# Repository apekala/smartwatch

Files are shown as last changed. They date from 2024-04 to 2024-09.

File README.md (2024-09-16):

# Smartwatch with Step Counter and BLE Connectivity

A smartwatch featuring a step counter, BLE connection for notifications, and automatic time synchronization with a mobile phone. This project includes a custom-designed PCB, firmware written in C using Zephyr RTOS, and a companion mobile app developed in Flutter.

## Features
- **Step Counter:** Tracks steps using the BMA456 accelerometer.
- **BLE Connectivity:** Connects to a mobile phone for notifications and time synchronization.
- **E-paper Display:** Provides a clear and power-efficient display.
- **Vibration Alerts:** Integrated vibration motor for notifications.
- **Custom 3D-Printed Case:** Durable and stylish housing for all components.

## Hardware Components
- **Custom PCB:** Designed to integrate all components seamlessly.
- **nRF52833 Microcontroller:** Handles processing and BLE communication.
- **npm1300 PMIC:** Power management for efficient battery usage.
- **BMA456 Accelerometer:** Used for accurate step counting.
- **E-paper Display:** Low-power display for showing time, steps, and notifications.
- **Vibration Motor:** Provides haptic feedback for notifications.
- **Li-Po Battery:** Rechargeable battery for powering the smartwatch.
- **3D-Printed Case:** Custom-designed to house the hardware.

## Software
- **Firmware:** Developed in C using Zephyr RTOS for reliable and real-time performance.
- **Mobile App:** Built with Flutter to handle BLE communication and manage smartwatch settings.
- **BLE Communication:** Allows the smartwatch to sync time and receive notifications from the phone.

# Pictures


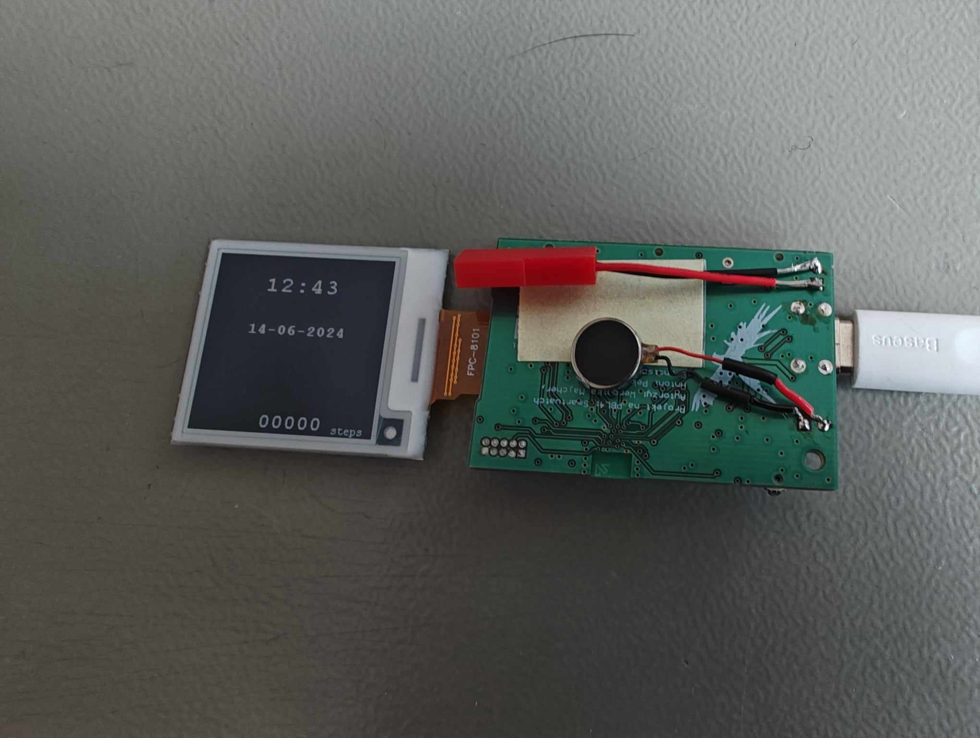
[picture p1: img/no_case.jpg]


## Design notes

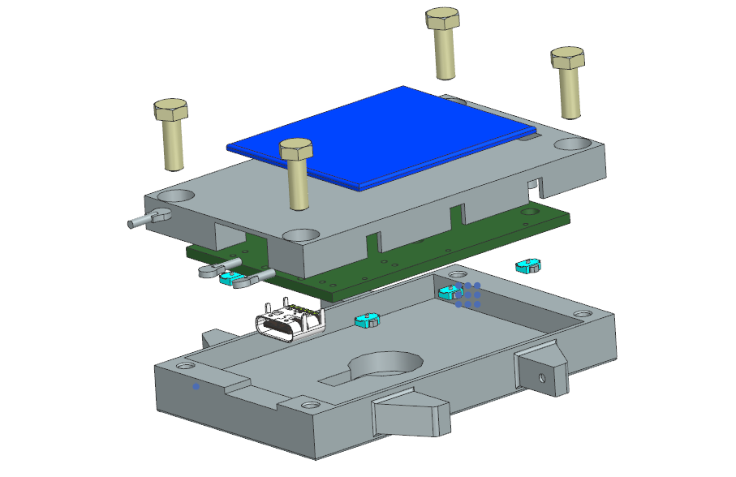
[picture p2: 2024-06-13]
MODEL/img/Explosion.png

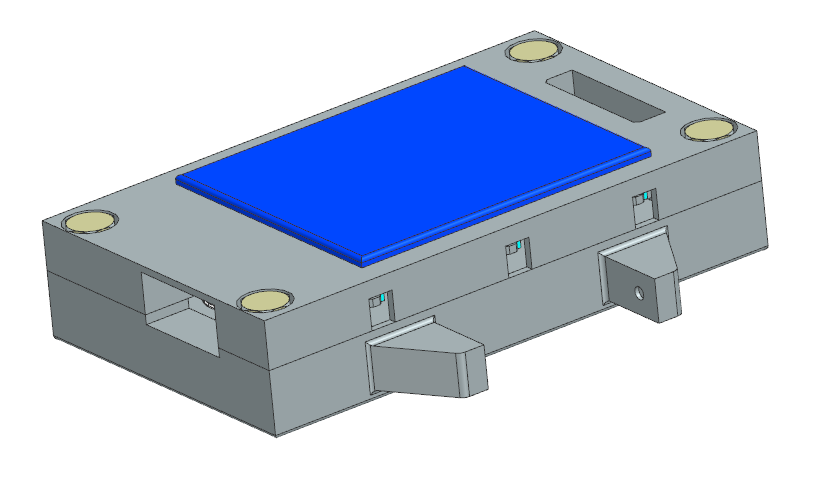
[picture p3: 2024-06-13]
MODEL/img/model.png

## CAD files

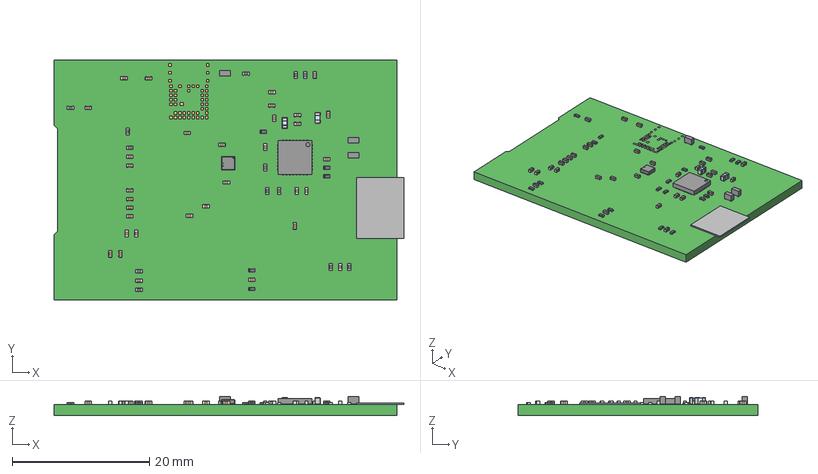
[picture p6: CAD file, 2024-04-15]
HARDWARE/PCB_smartwatch/Project Outputs for Free Documents/ExportSTEP/Demo_PCB.step
51.0 x 35.0 x 2.84 mm
User Library-res0402-1 x 18
User Library-cap_0402 x 33
ThermalPin
PinsArrayLR
PinsArrayTB
Extruded x 49
BOSCH logo
User Library-INDC1608X___ x 2
Pins x 3

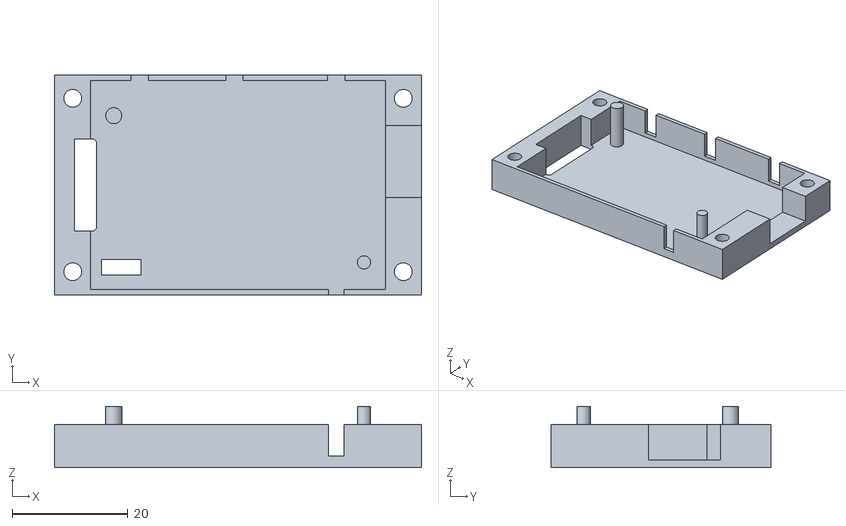
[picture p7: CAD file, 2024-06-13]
MODEL/STL/pokrywa_1.stl
63.5 x 38.0 x 10.6

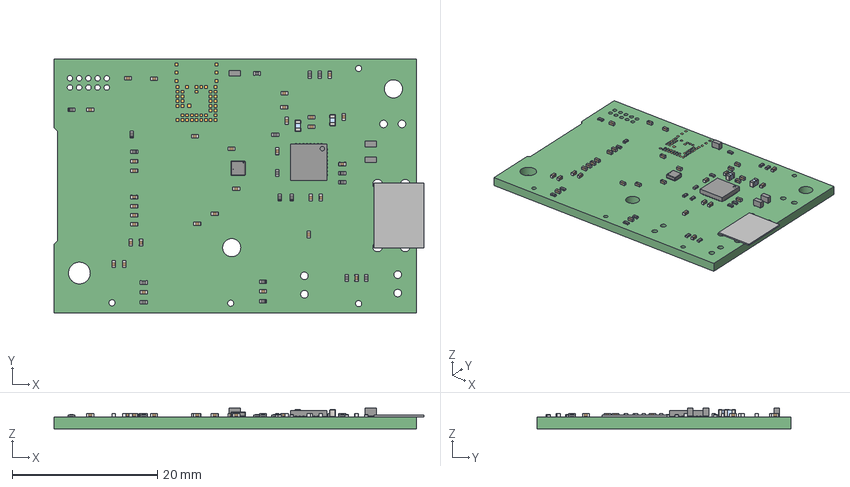
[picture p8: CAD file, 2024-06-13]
MODEL/smartwatch.step
51.0 x 35.0 x 2.84 mm
User Library-res0402-1 x 18
User Library-cap_0402 x 33
ThermalPin
PinsArrayLR
PinsArrayTB
Extruded x 49
BOSCH logo
User Library-INDC1608X___ x 2
Pins x 3

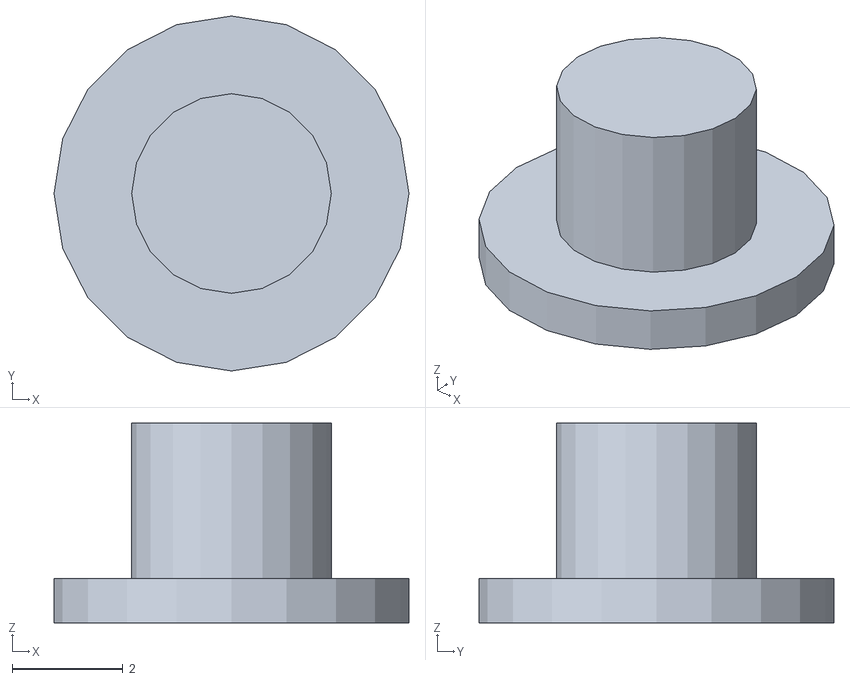
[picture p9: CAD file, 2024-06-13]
MODEL/STL/uszczelka2.stl
6.40 x 6.40 x 3.60

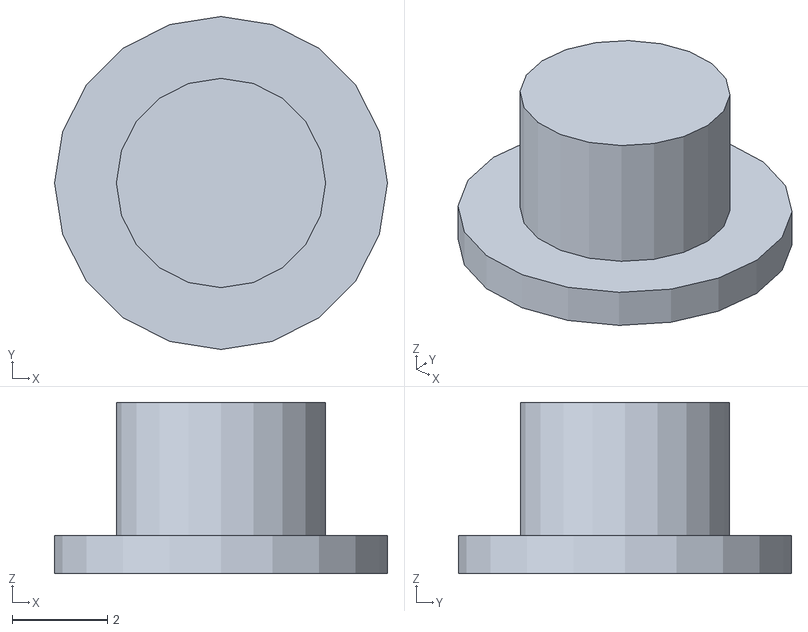
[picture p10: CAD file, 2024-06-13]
MODEL/STL/uszczelka.stl
7.00 x 7.00 x 3.60

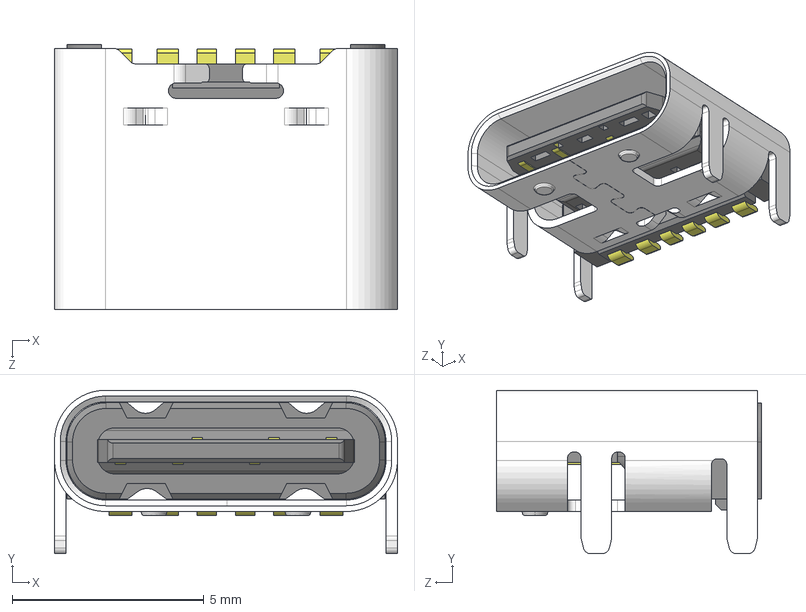
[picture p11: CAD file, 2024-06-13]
MODEL/UJC-HP2-3-SMT-TR.stp
8.94 x 4.26 x 6.90 mm

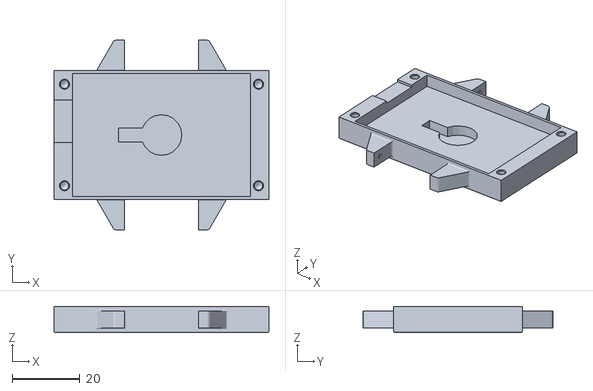
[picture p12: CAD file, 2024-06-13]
MODEL/STL/dolna_obudowa_3.stl
63.5 x 56.0 x 7.80

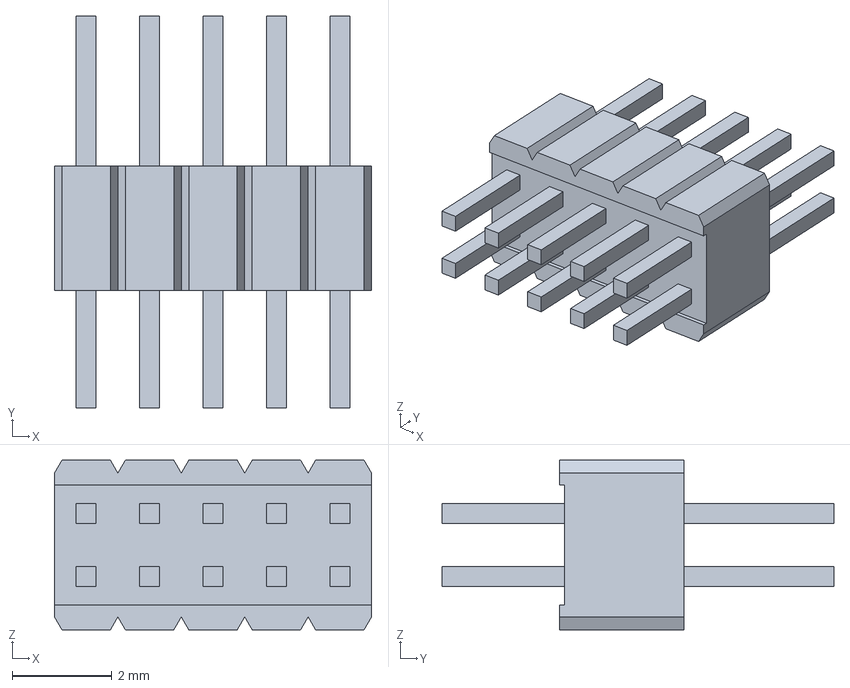
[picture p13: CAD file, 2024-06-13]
MODEL/20021111-00010T1LF.stp
6.35 x 7.85 x 3.40 mm

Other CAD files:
HARDWARE/PCB_smartwatch/Project Outputs for Free Documents/AutoCAD PCB/Demo_PCB.DWG
HARDWARE/PCB_smartwatch/Project Outputs for PCB_smartwatch/AutoCAD PCB/Demo_PCB.DWG
HARDWARE/PCB_smartwatch/Project Outputs for PCB_smartwatch/ExportSTEP/Demo_PCB.step
MODEL/1.prt
MODEL/2.prt
MODEL/20021111-00010T1LF_stp.prt
MODEL/3.prt
MODEL/6132891472.prt
MODEL/6132892112.prt
MODEL/6132898752.prt
MODEL/6263220400.prt
MODEL/6263222960.prt
MODEL/6263223120.prt
MODEL/BOSCH logo.prt
MODEL/Board.prt
MODEL/Body.prt
MODEL/Body19030.prt
MODEL/Body19596.prt
MODEL/C1.prt
MODEL/C10.prt
MODEL/C11.prt
MODEL/C12.prt
MODEL/C13.prt
MODEL/C14.prt
MODEL/C15.prt
MODEL/C16.prt
MODEL/C17.prt
MODEL/C18.prt
MODEL/C19.prt
MODEL/C2.prt
MODEL/C20.prt
MODEL/C21.prt
MODEL/C22.prt
MODEL/C23.prt
MODEL/C24.prt
MODEL/C25.prt
MODEL/C26.prt
MODEL/C27.prt
MODEL/C28.prt
MODEL/C29.prt
MODEL/C3.prt
MODEL/C30.prt
MODEL/C31.prt
MODEL/C32.prt
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

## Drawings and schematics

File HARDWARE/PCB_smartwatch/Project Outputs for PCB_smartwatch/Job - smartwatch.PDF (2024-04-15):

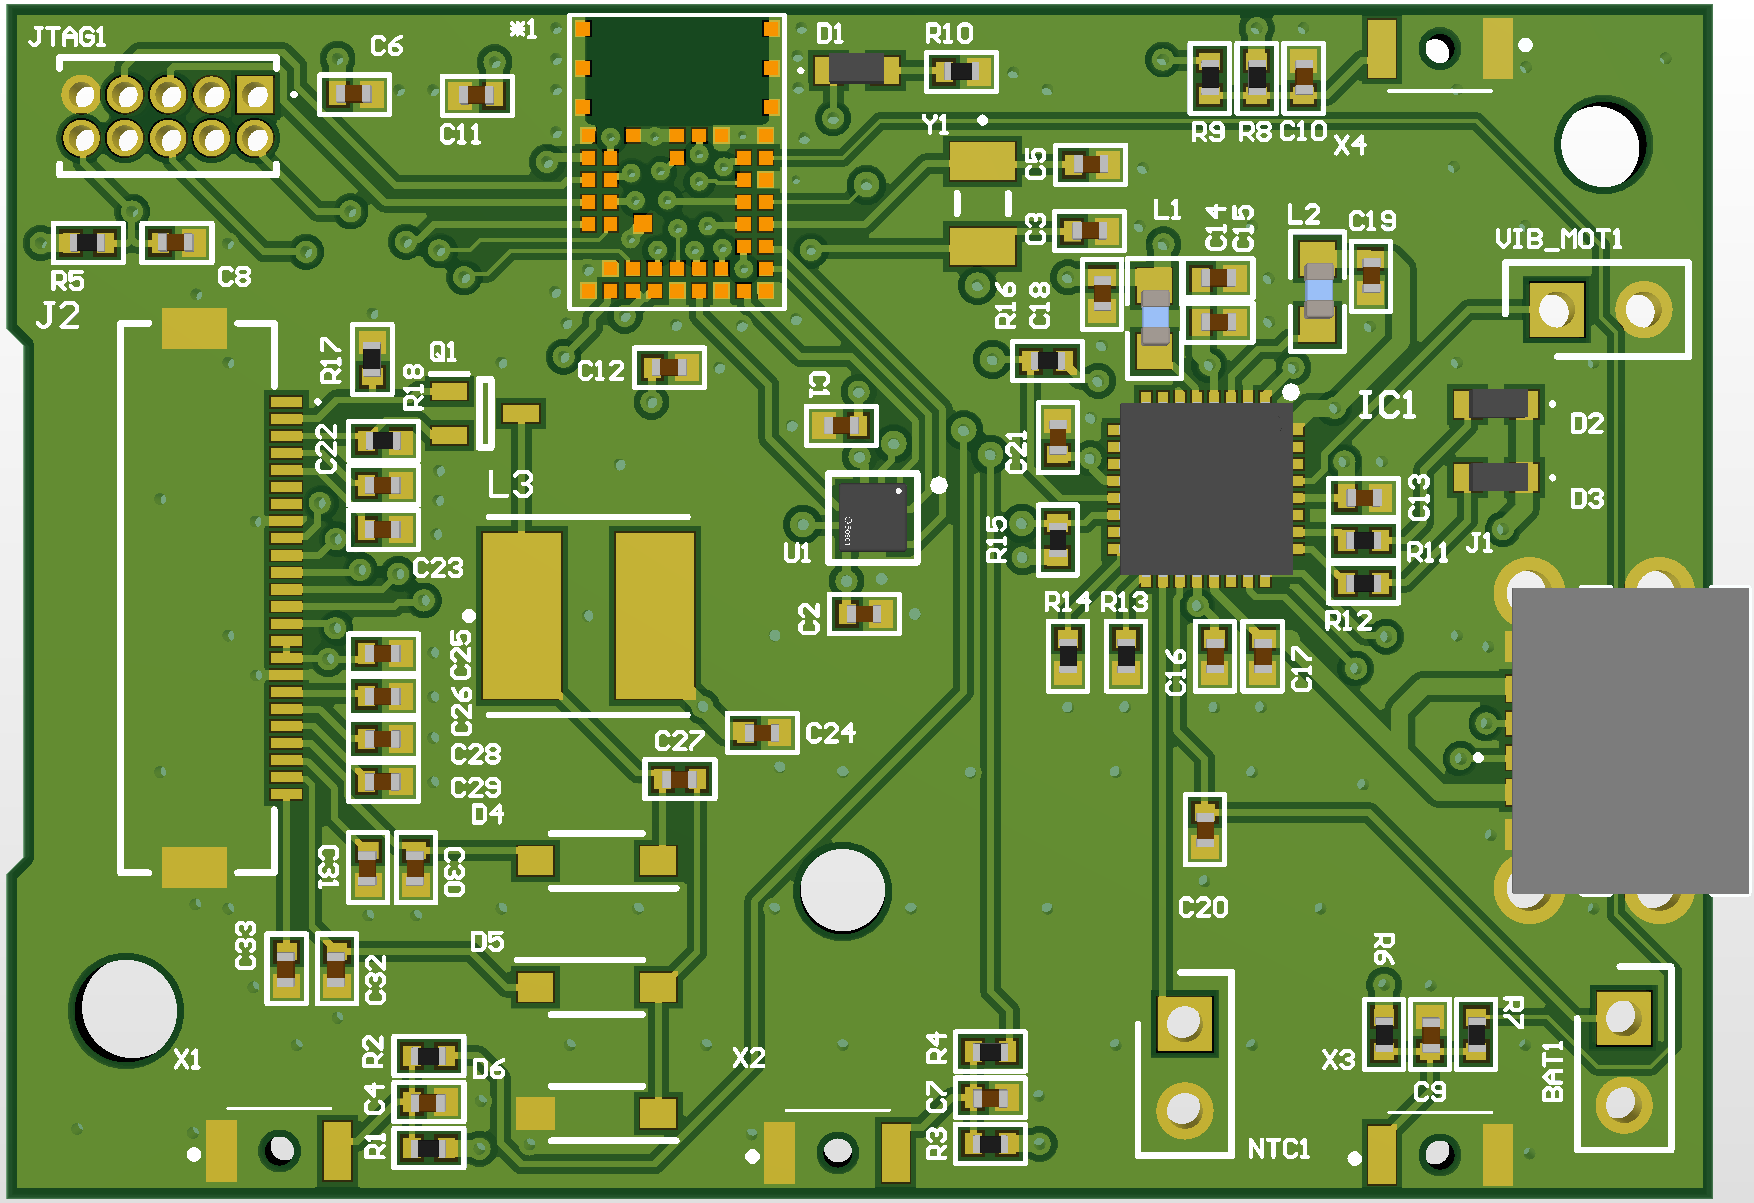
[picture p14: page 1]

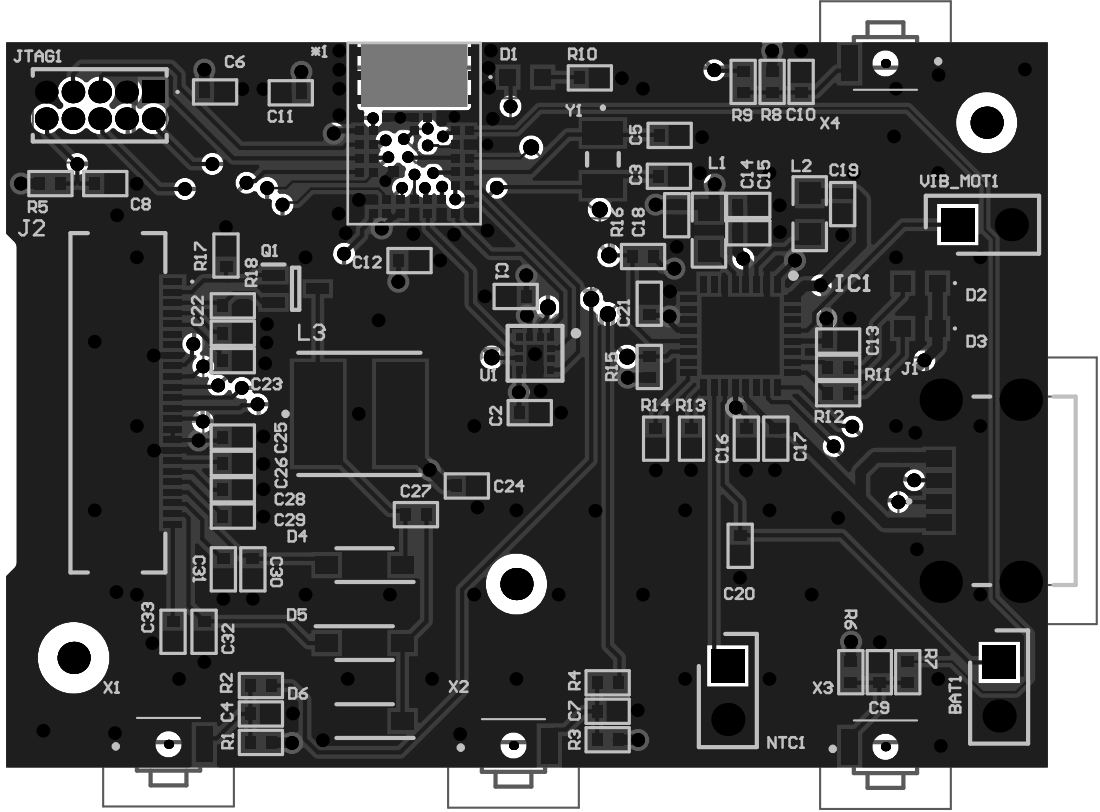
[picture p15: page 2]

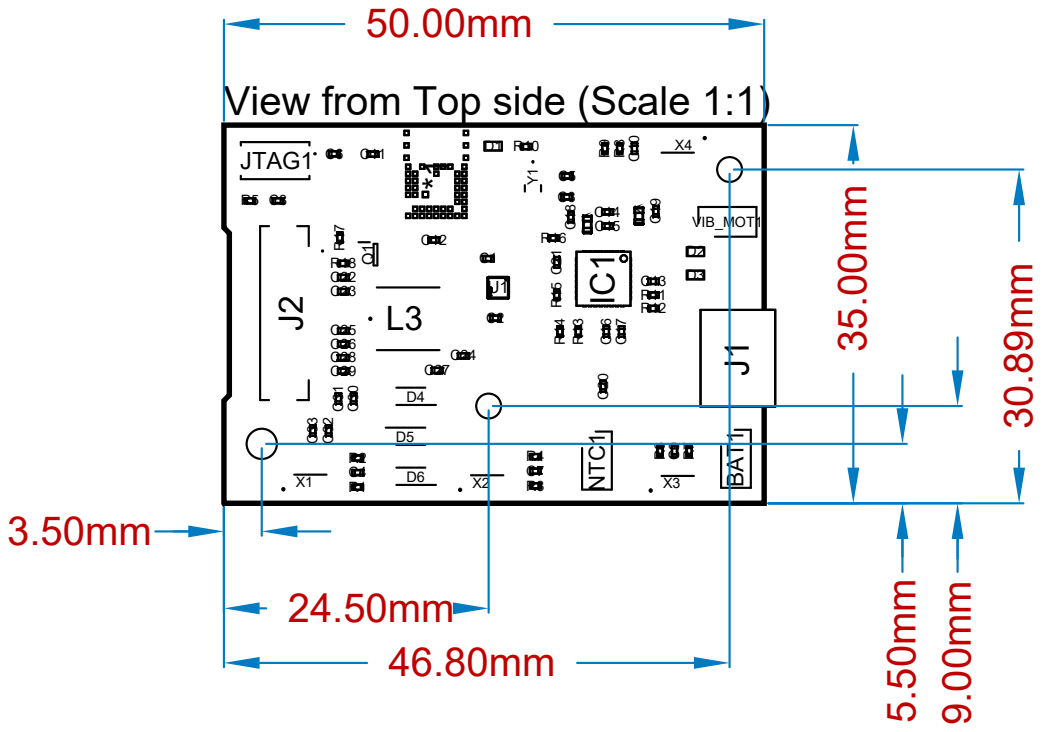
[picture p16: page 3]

View from Top side (Scale 1:1)
JTAG1J2

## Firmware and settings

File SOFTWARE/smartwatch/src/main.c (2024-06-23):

#include <zephyr/device.h>
#include <zephyr/devicetree.h>
#include <zephyr/drivers/counter.h>
#include <zephyr/drivers/gpio.h>
#include <zephyr/drivers/i2c.h>
#include <zephyr/kernel.h>
#include <zephyr/logging/log.h>
#include <zephyr/sys/printk.h>

#include "BLE/BLE.h"
#include "RTC/rtc.h"
#include "UI/display.h"
#include "UI/ui_controller.h"
#include "UI/vibration.h"
#include "accelerometer/accelerometer.h"
#include "power/npm1300.h"
#include "watch_controller/watch_controller.h"

#define DISPLAY_STACK_SIZE 16384
#define DISPLAY_THREAD_PRIORITY 5

K_THREAD_STACK_DEFINE(display_stack_area, DISPLAY_STACK_SIZE);
struct k_thread display_thread_data;

#define LED0_NODE DT_ALIAS(led0)
extern const struct gpio_dt_spec led = GPIO_DT_SPEC_GET(LED0_NODE, gpios);

LOG_MODULE_REGISTER(main, LOG_LEVEL_DBG);

int main(void) {
    int ret;
    if (!device_is_ready(led.port)) {
        return -1;
    }
    ret = gpio_pin_configure_dt(&led, GPIO_OUTPUT_ACTIVE);
    if (ret < 0) {
        return -1;
    }

    gpio_pin_set_dt(&led, 1);

    npm_init();
    k_msleep(1000);
    ui_vibration_init();

    ui_vibrate(1000);

    watch_init();
    rtc_init();
    accel_init();
    ble_init();

    k_tid_t my_tid = k_thread_create(&display_thread_data, display_stack_area,
                                     K_THREAD_STACK_SIZEOF(display_stack_area),
                                     ui_screen_refresh_thread,
                                     NULL, NULL, NULL,
                                     DISPLAY_THREAD_PRIORITY, 0, K_NO_WAIT);

    ui_init();

    watch_display_update();

    LOG_INF("Initialization complete");

    for (;;) {
        gpio_pin_toggle_dt(&led);
        k_msleep(100);
    }

    LOG_INF("end");
    return 0;
}

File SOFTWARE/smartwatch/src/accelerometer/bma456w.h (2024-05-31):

/**
* Copyright (c) 2023 Bosch Sensortec GmbH. All rights reserved.
*
* BSD-3-Clause
*
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
* 1. Redistributions of source code must retain the above copyright
*    notice, this list of conditions and the following disclaimer.
*
* 2. Redistributions in binary form must reproduce the above copyright
*    notice, this list of conditions and the following disclaimer in the
*    documentation and/or other materials provided with the distribution.
*
* 3. Neither the name of the copyright holder nor the names of its
*    contributors may be used to endorse or promote products derived from
*    this software without specific prior written permission.
*
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
* @file       bma456w.h
* @date       2023-07-05
* @version    V2.29.0
*
*/

/**
 * \ingroup bma4xy
 * \defgroup bma456w BMA456W
 * @brief Sensor driver for BMA456W sensor
 */

#ifndef BMA456W_H
#define BMA456W_H

#include <zephyr/logging/log.h>
#include <zephyr/logging/log_ctrl.h>

#ifdef __cplusplus
extern "C" {
#endif
#include "bma4.h"

/**\name Chip ID of BMA456W sensor */
#define BMA456W_CHIP_ID                                  UINT8_C(0x16)

/**\ Configuration ID start position of BMA456W sensor */
#define BMA456W_CONFIG_ID_START_ADDR                     UINT8_C(72)

/**\name Sensor feature size */
#define BMA456W_FEATURE_SIZE                             UINT8_C(76)
#define BMA456W_ANY_MOT_LEN                              UINT8_C(4)

/**\name Feature offset address */
#define BMA456W_ANY_MOT_OFFSET                           UINT8_C(0x00)
#define BMA456W_NO_MOT_OFFSET                            UINT8_C(0x04)
#define BMA456W_STEP_CNTR_PARAM_OFFSET                   UINT8_C(0x08)
#define BMA456W_STEP_CNTR_OFFSET                         UINT8_C(0x3A)
#define BMA456W_WRIST_WEAR_WAKEUP_OFFSET                 UINT8_C(0x3C)
#define BMA456W_WRIST_WEAR_WAKEUP_PARAM_OFFSET           UINT8_C(0x3E)
#define BMA456W_CONFIG_ID_OFFSET                         UINT8_C(0x48)
#define BMA456W_AXES_REMAP_OFFSET                        UINT8_C(0x4A)

/**\name Read/Write Lengths */
#define BMA456W_RD_WR_MIN_LEN                            UINT8_C(2)
#define BMA456W_NO_MOT_RD_WR_LEN                         (BMA456W_ANY_MOT_LEN + BMA456W_NO_MOT_OFFSET)

/*! @name Maximum valid read write length is size of config file array */
#define BMA456W_RD_WR_MAX_LEN                            ((uint16_t)sizeof(bma456w_config_file))

/**************************************************************/
/**\name    Step Counter/Detector/Activity */
/**************************************************************/
/**\name Step counter/activity enable macros */
#define BMA456W_STEP_CNTR_EN_MSK                         UINT8_C(0x10)
#define BMA456W_STEP_ACT_EN_MSK                          UINT8_C(0x20)

/**\name Step counter water-mark macros */
#define BMA456W_STEP_CNTR_WM_MSK                         UINT16_C(0x03FF)

/**\name Step counter reset macros */
#define BMA456W_STEP_CNTR_RST_POS                        UINT8_C(2)
#define BMA456W_STEP_CNTR_RST_MSK                        UINT8_C(0x04)

/**\name Step detector enable macros */
#define BMA456W_STEP_DETECTOR_EN_POS                     UINT8_C(3)
#define BMA456W_STEP_DETECTOR_EN_MSK                     UINT8_C(0x08)

/**\name Wrist-wear enable macros */
#define BMA456W_WRIST_WEAR_WAKEUP_EN_MSK                 UINT8_C(0x10)
#define BMA456W_WRIST_WEAR_WAKEUP_EN_POS                 UINT8_C(4)

/**\name Step count output length */
#define BMA456W_STEP_CNTR_DATA_SIZE                      UINT8_C(4)

/**************************************************************/
/**\name    Any/No-Motion */
/**************************************************************/
/**\name Any/No-motion threshold macros */
#define BMA456W_ANY_NO_MOT_THRES_MSK                     UINT16_C(0x07FF)

/**\name Any/No-motion duration macros */
#define BMA456W_ANY_NO_MOT_DUR_MSK                       UINT16_C(0x1FFF)

/**\name Any/No-motion enable macros */
#define BMA456W_ANY_NO_MOT_AXIS_EN_POS                   UINT8_C(0x0D)
#define BMA456W_ANY_NO_MOT_AXIS_EN_MSK                   UINT16_C(0xE000)

/**************************************************************/
/**\name    Wrist wear wakeup */
/**************************************************************/
/**\name Mask definition for minimum angle focus */
#define BMA456W_WRIST_WEAR_WAKEUP_MIN_ANG_FOCUS_MSK      UINT16_C(0xFFFF)

/**\name Mask definition for minimum angle non focus */
#define BMA456W_WRIST_WEAR_WAKEUP_MIN_ANG_NON_FOCUS_MSK  UINT16_C(0xFFFF)

/**\name Mask definition for angle landscape right */
#define BMA456W_WRIST_WEAR_WAKEUP_ANG_LSCAPE_RHT_MSK     UINT8_C(0xFF)

/**\name Mask definition for angle landscape left  */
#define BMA456W_WRIST_WEAR_WAKEUP_ANG_LSCAPE_LEFT_MSK    UINT16_C(0XFF00)

/**\name Position definition for angle landscape left */
#define BMA456W_WRIST_WEAR_WAKEUP_ANG_LSCAPE_LEFT_POS    UINT8_C(8)

/**\name Mask definition for angle portrait down  */
#define BMA456W_WRIST_WEAR_WAKEUP_ANG_PORTRAIT_DOWN_MSK  UINT8_C(0xFF)

/**\name Mask definition for angle portrait up */
#define BMA456W_WRIST_WEAR_WAKEUP_ANG_PORTRAIT_UP_MSK    UINT16_C(0xFF00)

/**\name Position definition for angle portrait up */
#define BMA456W_WRIST_WEAR_WAKEUP_ANG_PORTRAIT_UP_POS    UINT8_C(8)

/**\name Mask definition for minimum duration moved */
#define BMA456W_WRIST_WEAR_WAKEUP_MIN_DUR_MOVED_MSK      UINT8_C(0xFF)

/**\name Mask definition for minimum duration quite */
#define BMA456W_WRIST_WEAR_WAKEUP_MIN_DUR_QUITE_MSK      UINT16_C(0xFF00)

/**\name Position definition for minimum duration quite */
#define BMA456W_WRIST_WEAR_WAKEUP_MIN_DUR_QUITE_POS      UINT8_C(8)

/**************************************************************/
/**\name    User macros */
/**************************************************************/
/**\name Any-motion/No-motion axis enable macros */
#define BMA456W_X_AXIS_EN                                UINT8_C(0x01)
#define BMA456W_Y_AXIS_EN                                UINT8_C(0x02)
#define BMA456W_Z_AXIS_EN                                UINT8_C(0x04)
#define BMA456W_EN_ALL_AXIS                              UINT8_C(0x07)
#define BMA456W_DIS_ALL_AXIS                             UINT8_C(0x00)

/**\name Feature enable macros for the sensor */
#define BMA456W_STEP_CNTR                                UINT8_C(0x01)
#define BMA456W_STEP_ACT                                 UINT8_C(0x02)
#define BMA456W_WRIST_WEAR_WAKEUP                        UINT8_C(0x04)

/**\name Interrupt status macros */
#define BMA456W_STEP_CNTR_INT                            UINT8_C(0x02)
#define BMA456W_ACTIVITY_INT                             UINT8_C(0x04)
#define BMA456W_WRIST_WEAR_WAKEUP_INT                    UINT8_C(0x08)
#define BMA456W_ANY_MOT_INT                              UINT8_C(0x20)
#define BMA456W_NO_MOT_INT                               UINT8_C(0x40)
#define BMA456W_ERROR_INT                                UINT8_C(0x80)
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

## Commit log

2024-03-19 add empty project
    [PCB_smartwatch.PrjPcb]
2024-03-19 add acceletometer schema
    [PCB_smartwatch.PrjPcb, Schlib1.SchLib, accelerometer.SchDoc]
2024-03-20 add vibration schema
    [Schlib1.SchLib, accelerometer.SchDoc]
2024-03-20 add lfxo oscilator schema
    [32.768_crystal.SchDoc, PCB_smartwatch.PrjPcb, Schlib1.SchLib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]
2024-03-20 import button
    [32.768_crystal.SchDoc, PCB_smartwatch.PrjPcb, accelerometer.SchDoc]
2024-03-20 chance oscilator capacitor value to 18pF
    [32.768_crystal.SchDoc, PCB_smartwatch.PrjPcb, Schlib1.SchLib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]
2024-03-21 Add e-Paper
    [PCB_smartwatch.PrjPcb, e-Paper.PcbLib, e-Paper.SchLib]
2024-03-21 Add NPM1300
    [PCB_smartwatch.PrjPcb, usb.SchDoc, zasilanie.SchDoc]
2024-03-21 npm1300 ready for final check
    [PcbLib-zasilanie.PcbLib, Schlib-zasilanie.SchLib, Schlib1-zasilanie.SchLib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]
2024-03-21 Add BL653, Rename display
    [1.54inch_e-Paper.SchDoc, BL653.SchDoc, BL653u.PcbLib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]
2024-03-21 Remove crystal, Add BL635 ports e-Paper and accelerometer
    [1.54inch_e-Paper.SchDoc, 32.768_crystal.SchDoc, BL653.SchDoc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]
2024-03-21 Update e-Paper library
    [e-Paper.SchLib]
2024-03-21 Add JTAG
    [BL653.SchDoc, BL653u.PcbLib, BL653u.SchLib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]
2024-03-22 npm1300 modified, usb sheet no longer needed
    [Schlib1-zasilanie.SchLib, usb.SchDoc, zasilanie.SchDoc]
2024-03-22 Add Footprints
    [1.54inch_e-Paper.SchDoc, BL653.SchDoc, BL653u.PcbLib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]
2024-03-22 Add zasilanie I2C Ports and VCC
    [BL653.SchDoc, PCB_smartwatch.PrjPcb, usb.SchDoc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]
2024-03-22 consultations with Dominik
    [Schlib1-zasilanie.SchLib, zasilanie.SchDoc]
2024-03-22 cosmetic changes in npm1300
    [PCB_smartwatch.PrjPcb, zasilanie.SchDoc]
2024-03-26 libraries and footprints - power
    [PCB_smartwatch.PrjPcb, PcbLib-zasilanie.PcbLib, Schlib1-zasilanie.SchLib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]
2024-03-27 layers in footprints configured - npm and usb
    [PcbLib-zasilanie.PcbLib, Schlib1-zasilanie.SchLib, e-Paper.PcbLib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]
2024-03-27 Add inductor footprint, change resistor schamtic, Add templates parameters
    [1.54inch_e-Paper.SchDoc, BL653.SchDoc, BL653u.SchLib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]
2024-03-28 add buttons and led
    [BL653.SchDoc, Schlib1.SchLib, accelerometer.SchDoc]
2024-03-28 changes in power library, inne pcb library added, slight corrections in footprints
    [BL653.SchDoc, BL653u.PcbLib, PCB_smartwatch.PrjPcb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]
2024-03-28 bl changed to 2.5 mm
    [1.54inch_e-Paper.SchDoc, BL653.SchDoc, BL653u.SchLib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]
2024-03-29 pcb_demo.pcbdoc added
    [Demo_PCB.PcbDoc]
2024-03-29 ready to be send, although some footprints missing - to be asked
    [BL653.SchDoc, PCB_smartwatch.PrjPcb, Schlib1-zasilanie.SchLib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]
2024-04-01 small changes + ntc footprint
    [1.54inch_e-Paper.SchDoc, BL653.SchDoc, Schlib1-zasilanie.SchLib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]
2024-04-01 crystal libraries added and notes - whats missing
    [1.54inch_e-Paper.SchDoc, BL653.SchDoc, PCB_smartwatch.PrjPcb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]
2024-04-02 bma libraries added
    [BL653.SchDoc, PCB_smartwatch.PrjPcb, accelerometer.SchDoc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]
2024-04-03 footprints have same colors, switches and crystal added
    [1.54inch_e-Paper.SchDoc, B3U-3000PM-B.SchLib, B3U3000PMB.PcbLib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]
2024-04-03 less libraries
    [B3U-3000PM-B.SchLib, B3U3000PMB.PcbLib, BL653u.PcbLib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]
2024-04-03 less libraries configured
    [BL653.SchDoc, BL653u.PcbLib, BL653u.SchLib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]
2024-04-03 mils to mm in e-paper
    [1.54inch_e-Paper.SchDoc, BL653.SchDoc, Schlib1-zasilanie.SchLib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]
2024-04-03 vcc to vddio in accelerometer (send to be checked by tutor)
    [accelerometer.SchDoc]
2024-04-04 less warnings now
    [1.54inch_e-Paper.SchDoc, BL653.SchDoc, BL653u.SchLib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]
2024-04-05 main components on pcb placed
    [Demo_PCB.PcbDoc, Schlib1-zasilanie.SchLib, zasilanie.SchDoc]
2024-04-05 Fix tutor comments
    [1.54inch_e-Paper.SchDoc, BL653.SchDoc, BL653u.SchLib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]
2024-04-05 Fix wires BS
    [1.54inch_e-Paper.SchDoc]
2024-04-05 intial placing of components
    [Demo_PCB.PcbDoc]
2024-04-05 placing of components v2
    [1.54inch_e-Paper.SchDoc, Demo_PCB.PcbDoc, PCB_smartwatch.PrjPcb]
2024-04-05 vib-motor pins
    [1.54inch_e-Paper.SchDoc, BL653.SchDoc, Demo_PCB.PcbDoc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]
2024-04-07 2 pcb layout propositions
    [1.54inch_e-Paper.SchDoc, BL653.SchDoc, Copy of Demo_PCB.PcbDoc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]
2024-04-08 pcb redesigning
    [1.54inch_e-Paper.SchDoc, BL653.SchDoc, Copy of Demo_PCB.PcbDoc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]
2024-04-09 redesign of pcb
    [1.54inch_e-Paper.SchDoc, BL653u.PcbLib, Copy of Demo_PCB.PcbDoc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]
2024-04-09 Fix Capacitors name, Fix BL653u power suply
    [1.54inch_e-Paper.SchDoc, BL653.SchDoc, e-Paper.SchLib]
2024-04-11 redefining pins, completing the pcb layout, backups
    [1.54inch_e-Paper.SchDoc, BL653.SchDoc, BL653u.PcbLib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]
2024-04-12 final changes
    [1.54inch_e-Paper.SchDoc, BL653.SchDoc, BL653u.PcbLib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]
2024-04-12 buttons pullups added
    [1.54inch_e-Paper.SchDoc, BL653.SchDoc, BL653u.PcbLib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]
2024-04-12 smaller vias, no more warnings - to be double checked
    [BL653u.PcbLib, Demo_PCB.PcbDoc, PCB_smartwatch.PrjPcb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]
2024-04-14 pins for crystal changed, changes in accordance with tutors advice
    [BL653.SchDoc, Demo_PCB.PcbDoc, accelerometer.SchDoc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]
2024-04-15 fabrication files completed
    [BL653.SchDoc, Demo_PCB.PcbDoc, PCB_smartwatch.PrjPcb]
2024-04-15 project outputs added
    [Demo_PCB.DWG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]
2024-04-17 measurements for package design
    [BL653u.PcbLib, Demo_PCB.PcbDoc, PCB_smartwatch.PrjPcb]
2024-05-23 Add PCB model, Add buttons
    [1.prt, 2.prt, 3.prt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]
2024-05-26 Add first version of smartwatch case
    [20021111-00010T1LF.stp, 20021111-00010T1LF_stp.prt, 6263223120.prt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]
2024-05-26 Add some edge blend
    [Smartwatch.prt]
2024-05-30 add BLE connection and Step Counter Service, currently returning static data
2024-06-07 fix clock uptate. now diplay updates at the moment of update, and next updatest are perwormed when sencons-00
    [main.c]
2024-06-07 bma works on pcb
2024-06-12 add vibration on button press
    [common.c, main.c, npm1300.c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]
2024-06-13 displaying notififcations (buggy navigation, no line wrap)
    [epdif.c]
2024-06-13 Change model to reverse dispaly
    [6132892112.prt, Board.prt, Smartwatch.prt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]
